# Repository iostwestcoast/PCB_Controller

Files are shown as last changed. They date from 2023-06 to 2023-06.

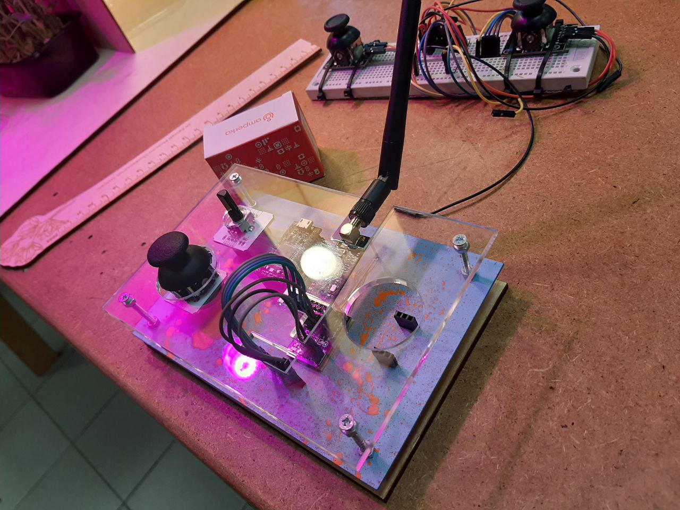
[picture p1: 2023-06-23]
Photos & Videos & Screenshots/photo_2023-06-23_14-38-17.jpg

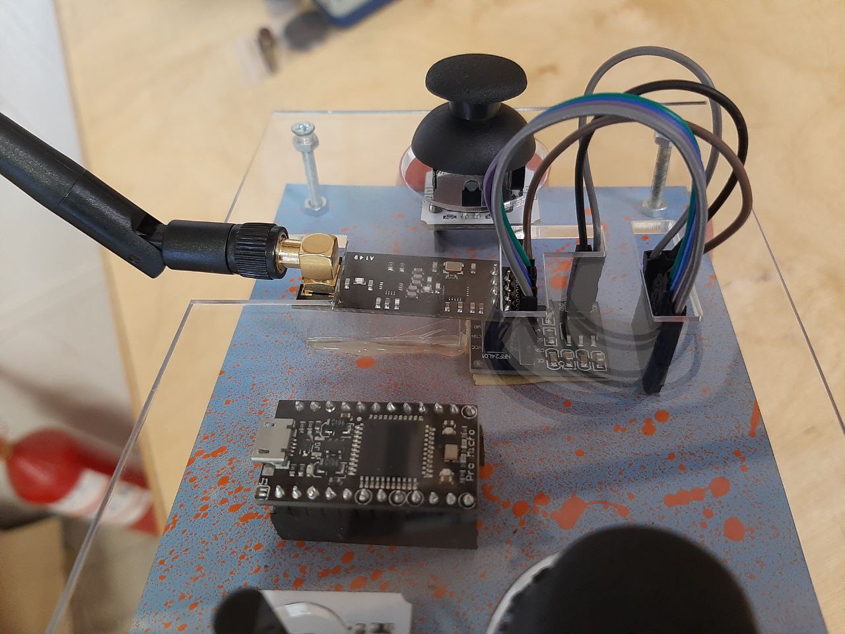
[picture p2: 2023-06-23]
Photos & Videos & Screenshots/photo_2023-06-23_14-38-27.jpg

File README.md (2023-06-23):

# PCB Controller

PCB controller based on an arduino made with a milling machine designed for a radio controlled bot

The final look of the controller:



https://github.com/iostwestcoast/PCB_Controller/assets/114690482/6b196048-b7b7-4629-8197-2101ce62043e

Сomponents:

- NRF+

- Arduino Pro Micro

- x2 joystick

- potentiometer

- powerbank

Work plan:

- In EasyEDA add the required electronic components and connect them
- Trace and correct the tracks for the PCB, 1 mm indentation and 0.8 mm track thickness
- Download a .dxf file and remove unnecessary vectors with the Rhino program
- Correct vectors in Rhino or ArtCAM and mirror the whole schematic
- Make milling on CNC machine, prepare file and paths in ArtCAM
- We mill the holes for the pins through, mill 0.5mm, mill the tracks 0.2mm deep, mill 0.3mm tapered
- Since the PCB is double sided and the second layer is not needed, we remove it completely with the 6mm mill
- Solder the pins to the board according to the holes and install the components
- The design can be absolutely whatever you want
- In this case I painted the front part before soldering and cut out a transparent cover plate from acrylic on a laser machine, it is fastened with screws

Scematics:



PCB:



ArtCAM:



Milling:



Painting:



Soldering:



Acrylic panel:

photo_2023-06-23_14-38-37 (2)

PCB Controller code:

```C++
#include <SPI.h>
#include <nRF24L01.h>
#include <RF24.h>

RF24 radio(8, 10);
int data[3];

#define PIN_VRX A2
#define PIN_VRY A3

void setup() {
  Serial.begin(9600);

  radio.begin();
  radio.setChannel(1);
  radio.setDataRate(RF24_1MBPS);
  radio.setPALevel(RF24_PA_HIGH);
  radio.openWritingPipe(0x2234567890LL);
  radio.stopListening();

  pinMode(A1, INPUT);
}

void loop() {
  int potval = analogRead(A1);

  radio.write(&data, sizeof(data));
  delay(50);

  Serial.println(potval);
     
  int valX = analogRead(PIN_VRX);
  int valY = analogRead(PIN_VRY);

  Serial.print("X = ");
  Serial.println(analogRead(PIN_VRX));

  Serial.print("Y = ");
  Serial.println(analogRead(PIN_VRY));

  data[0] = potval;
  data[1] = valX;
  data[2] = valY;
}
```

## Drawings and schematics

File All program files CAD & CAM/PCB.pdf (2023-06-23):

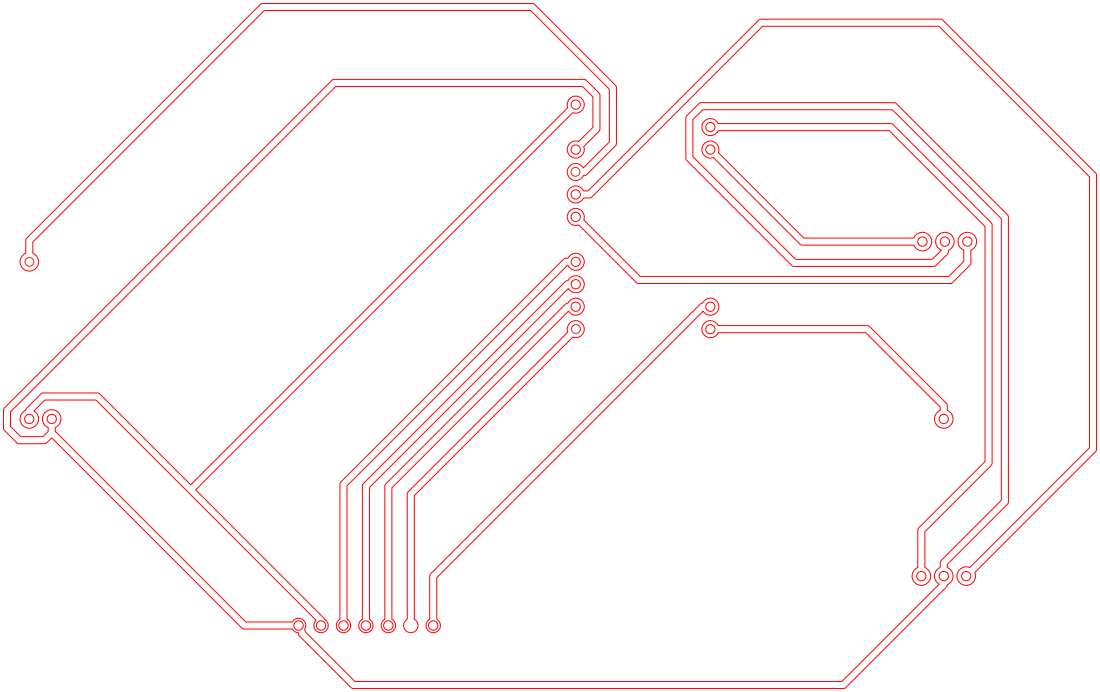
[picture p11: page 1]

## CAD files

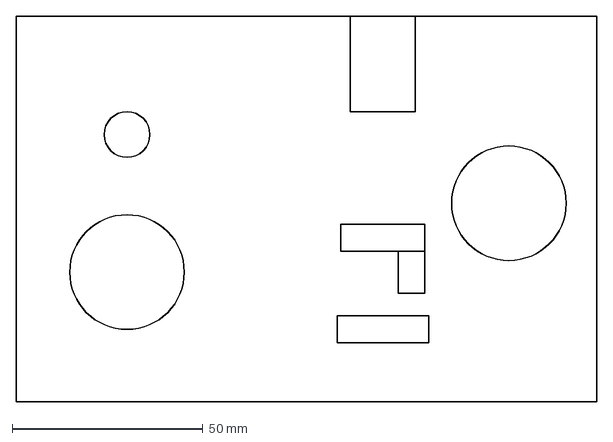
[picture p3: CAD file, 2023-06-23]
All program files CAD & CAM/akril/akril.DXF
152.0 x 101.0 mm

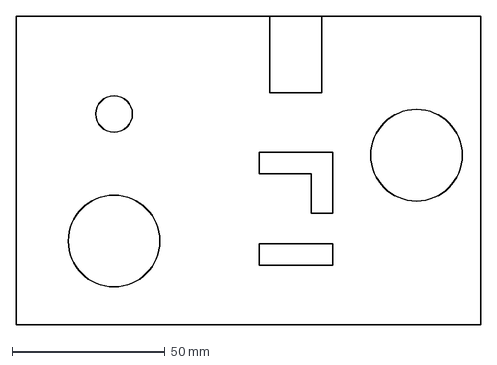
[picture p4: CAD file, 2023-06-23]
All program files CAD & CAM/akril1.DXF
152.0 x 101.0 mm

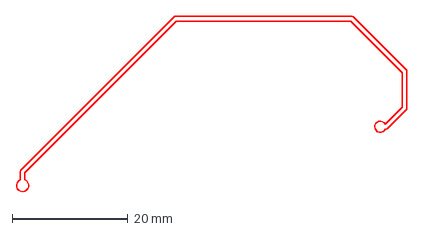
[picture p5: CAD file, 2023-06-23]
All program files CAD & CAM/PCB True1.dxf
67.6 x 30.3 mm

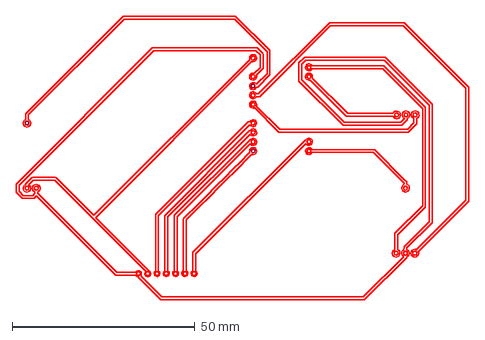
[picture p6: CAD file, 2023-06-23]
All program files CAD & CAM/2.dxf
123.7 x 77.5 mm

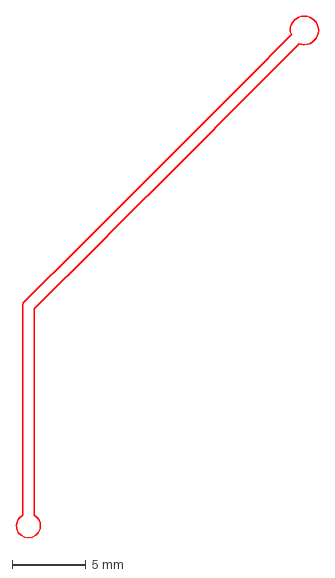
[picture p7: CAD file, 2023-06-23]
All program files CAD & CAM/PCB1234.dxf
20.5 x 35.3 mm

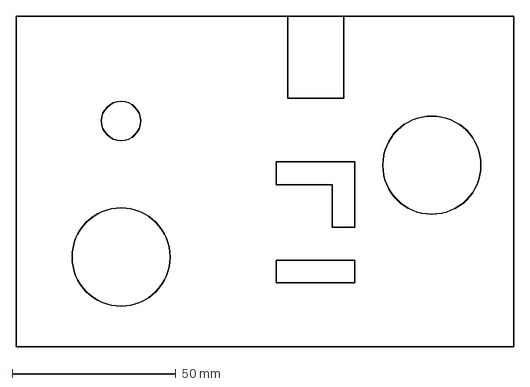
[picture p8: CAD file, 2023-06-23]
All program files CAD & CAM/akril2.DXF
152.0 x 101.0 mm

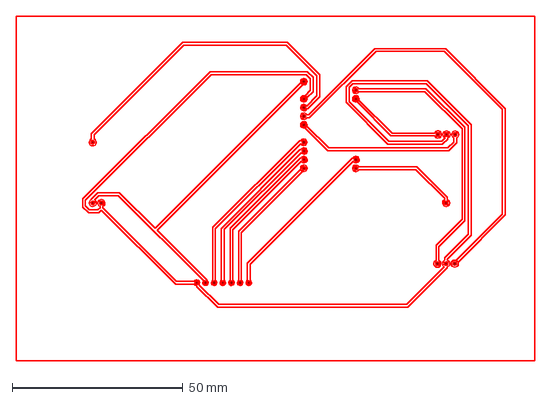
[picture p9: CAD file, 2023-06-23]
All program files CAD & CAM/pcb.dxf
152.0 x 101.0 mm

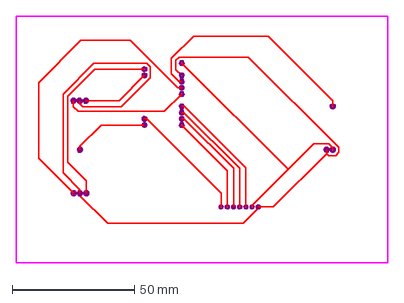
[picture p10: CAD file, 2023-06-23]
All program files CAD & CAM/PCB_pcbic.dxf
152.0 x 101.0 mm

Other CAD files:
All program files CAD & CAM/PCB_pcbic_2_2023-06-19.dxf
All program files CAD & CAM/PCB_pcbic_2_2023-06-19.3dm
All program files CAD & CAM/akril.SLDDRW
All program files CAD & CAM/akril/akril.SLDDRW
All program files CAD & CAM/akril1.SLDDRW
